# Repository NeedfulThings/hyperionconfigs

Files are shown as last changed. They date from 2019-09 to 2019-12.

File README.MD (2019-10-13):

# Hyperion uses framegrabber on Kodi
* Drives **WS2812B** Led stripes
* **45 LEDS** activated 170 incative to be activated
* **xbmcVideoChecker** is **activated** to communicate to **Kodi**
  64 * 64 Pixel @ 60 Hz
* **Smoothing** Linear 96ms @ Update Freq 48k

---

# Get the code
```BASH 
git clone --recurse-submodules
git@github.com:NeedfulThings/hyperionconfigs.git
```

# Setup the dev environment
 
We are using direnv to get a clean environment that can have oher versions than the rest of your system. It's required to set it up first and configure well.

## Install direnv

### Linux
```BASH
curl -qfsSL https://github.com/direnv/direnv/releases/download/v2.19.0/direnv.linux-amd64 -o direnv
chmod +x direnv
sudo mv direnv /usr/local/bin
```

### macOS
```BASH
brew install dirvenv
```

## Hook it up in your shell
### BASH
*add the following line to your `~/.bashrc` file*
```BASH
eval "$(direnv hook bash)"
```
### ZSH
*add the following line to your `~/.zshrc` file*
```BASH
eval "$(direnv hook zsh)"
```
### Other shells

*Take a look [here](https://github.com/direnv/direnv/blob/master/docs/hook.md)*

## Setup the dev environment by just running
```BASH
./start.sh
```
in the Project root

---

# USB Arduino Uno
Folder *USB-ArduinoUno*

* Sketch for **Arduino Uno R3**
* uses **FastLED** lib
* set to **45 LED**
* Speaks SPI on Digital **Pin 6**
* Baudrate is set to **500k baud**
* Type **adalight**
* Output to **USB Port** /ttyUSB0 
* Colororder **grb**

## Install

### `hyperion.config.json`

copy the `L45_Config/hyperion.config.json` to your `/storage/.config` folder

### `hyperion_ws2812.ino`

Install the `hyperion_ws2812.ino` on your Arduino. You can use the Makefile inside the folder by just running ```make upload```

---

# USB Arduino Nano
Folder *USB-ArduinoNano*

* Sketch for **Arduino Nano**
* uses **FastLED** lib
* set to **128 LED**
* Uses Digital **Pin 11**
* Baudrate is set to **500k baud**
* Type **adalight**
* Output to **USB Port** /ttyUSB0 
* Colororder **grb**

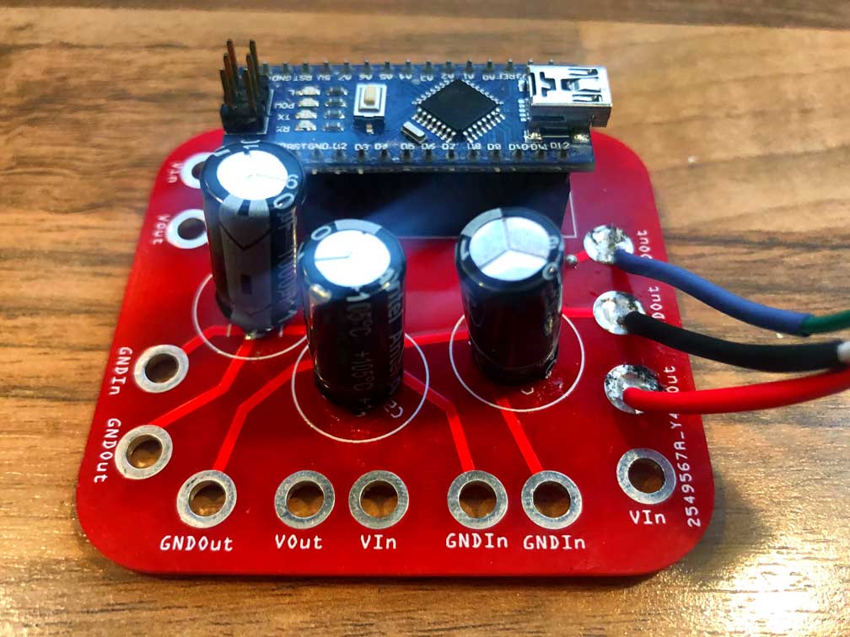
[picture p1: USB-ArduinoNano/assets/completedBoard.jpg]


## Install

### `FS128_Config`

copy the `hyperion.config.json` to your `/storage/.config` folder

### `hyperion_ws2812.ino`

Install the `hyperion_ws2812.ino` on your Arduino. You can use the Makefile inside the folder by just running ```make upload```

### `Hardware`

Take a look into the USB-ArduinoNano.md file to get more informations

---

# UDP / Network ESP8266
 Folder *UDP-ESP8266*
 * Type **udp**
 * Protocol **0**
 * Port **19446**
 * set to **45 LED** supports up to 490 inn hyperion mode

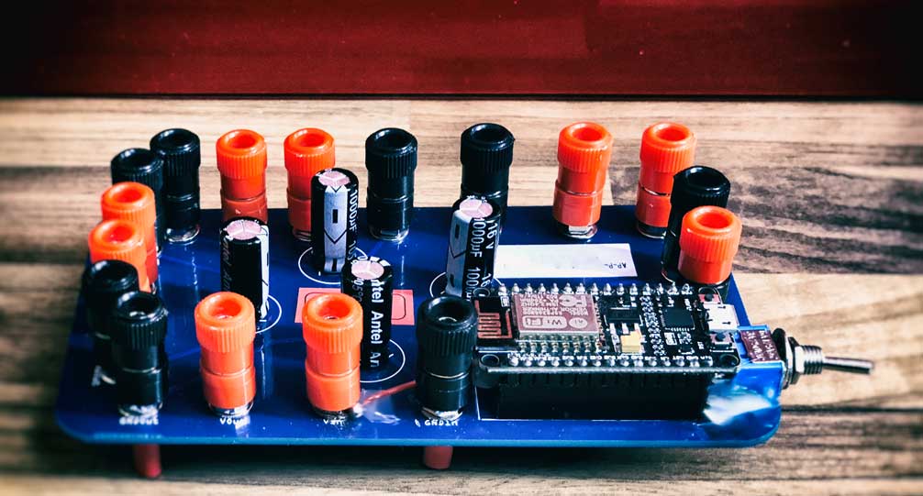
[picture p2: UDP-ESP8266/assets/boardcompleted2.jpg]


## Install

### `hyperion.config.json`

Copy the `hyperion.config.json` to your `/storage/.config` folder

### `WLED`

Install from the submobule folder [Aircoookie](https://github.com/Aircoookie)'s [WLED](https://github.com/Aircoookie/WLED) 

If you want to get it as binary you can find the latest relases [here](https://github.com/Aircoookie/WLED/releases)

Further Infos can be found in the [Wiki](htpps://github.com/Aircoookie/WLED/wiki)

---

# Directly via GPIO

 Folder *PI-GPIO*
 * Type **ws281x**
 * set to **45 LED**
 * Speaks PWM 0 on **GPIO12 (PIN 32)**
 * Colororder **grb**

## Install

### `hyperion.config.json`

copy the `hyperion.config.json` to your `/storage/.config` folder

### `SD` 

copy the `config.txt` from `SD` or at least the last lines below the `End of default configuration Block` directly to your **SD Card** while it's **NOT** running in the pi

### `etc`

copy the file `snd-blacklist.conf` to your **running** pi `/etc/modprobe.d/` - The easiest way copy etc to your / 

Now **reboot** - When your pi is up again, check with `aplay -l`if you can still see a soundcard.

If yes you might want to `blacklist snd_bcm2835` as last line to `/etc/modprobe.d/alsa-blacklist.conf`, reboot and check again.

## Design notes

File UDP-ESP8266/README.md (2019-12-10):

# Hyperion via UDP to ESP8266

## Flash Arduino
File for Arduino IDE located in `WLED`

## Setup Hyperion on PI
The `hyperion.config.json` file in this folder is setup for a 64 LED Background with no bottom.

So go get HyperCon.jar and generate a led setup what matches your setup, ignore everything else. You just need the led setup and generate a config with it. Now mark everything from 
`"leds" :`
until
`],`
and copy it. 

Go to the hyperion.config.json in this folder and replace the lines 99 - 426 with the just copied content.

Et voila, you are ready to go.
Put the file on your pi in `/storage/.config/`

## PCB & Breadboard

I created a pcb for the ESP8266 Dev Board called NodeMCU 0.9. It's a setup with 4 Power Injectors, +/- each protected by a 1000 µF capacitor leading to 4 Power Outs +/- and one Dataline connected to the D4 Port of the NodeMCU and protected with a 470Ω Resistor.

If you need to build your hardware, go to layout, there you can find:

 * Fritzing file `tvbacklightesp8266_v1.2.fzz` 

 * Gerber to get my PCB Layout manufactured

### v1.0
  * Full working layout

### v1.1
  * added Switch to power the NodeMcu with the 5V Power from the injectors

### v1.2
  * added multiple Jumper to that can be used instead of up to 3 capacitors. That enables one powerinput with all 4 power outputs for every edge of the screen.

### v1.3
  * added mountingholes
  * redesigned for a smaller form factor
  * add solderjumper

### Rendered from Gerber
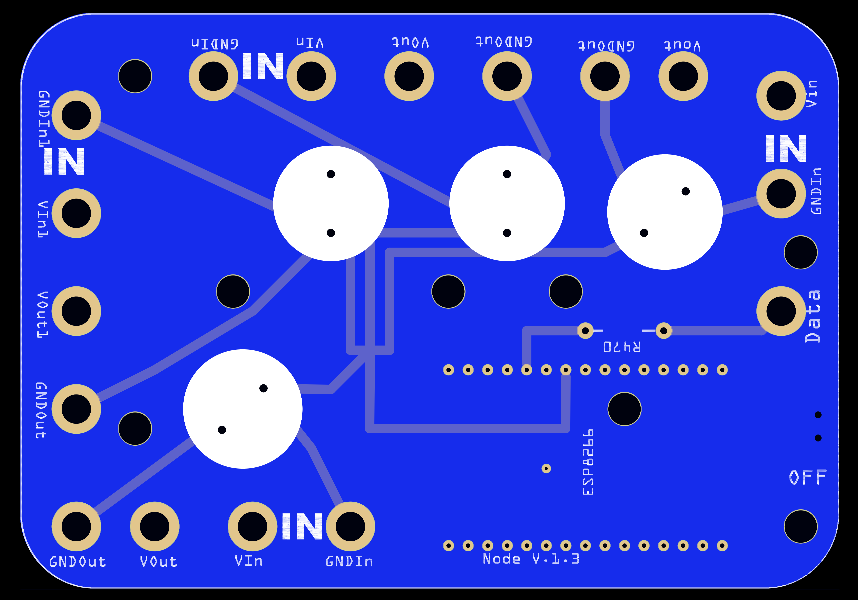
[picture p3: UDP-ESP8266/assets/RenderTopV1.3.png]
gerber_render_top_v1.3
 
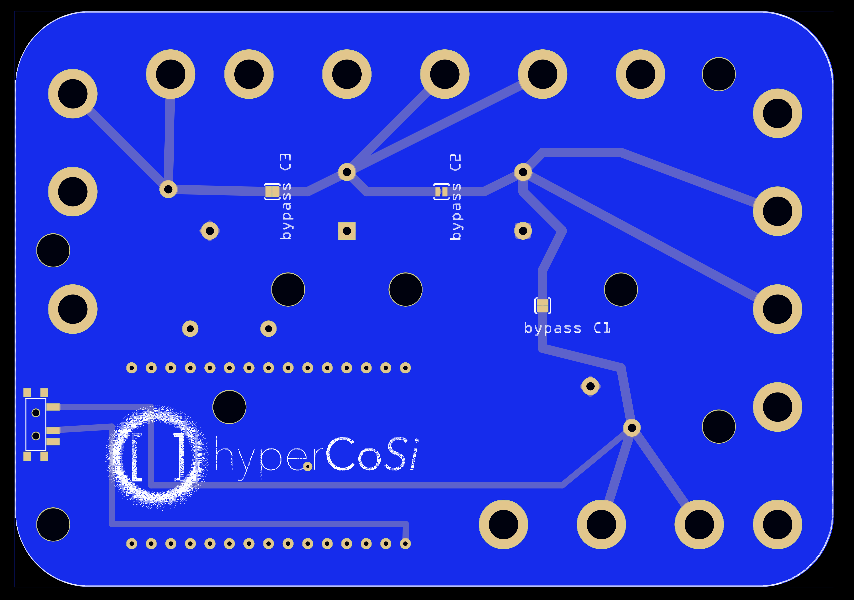
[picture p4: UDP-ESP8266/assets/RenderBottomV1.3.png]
gerber_render_bottom_v1.3

 
### Real PCBs
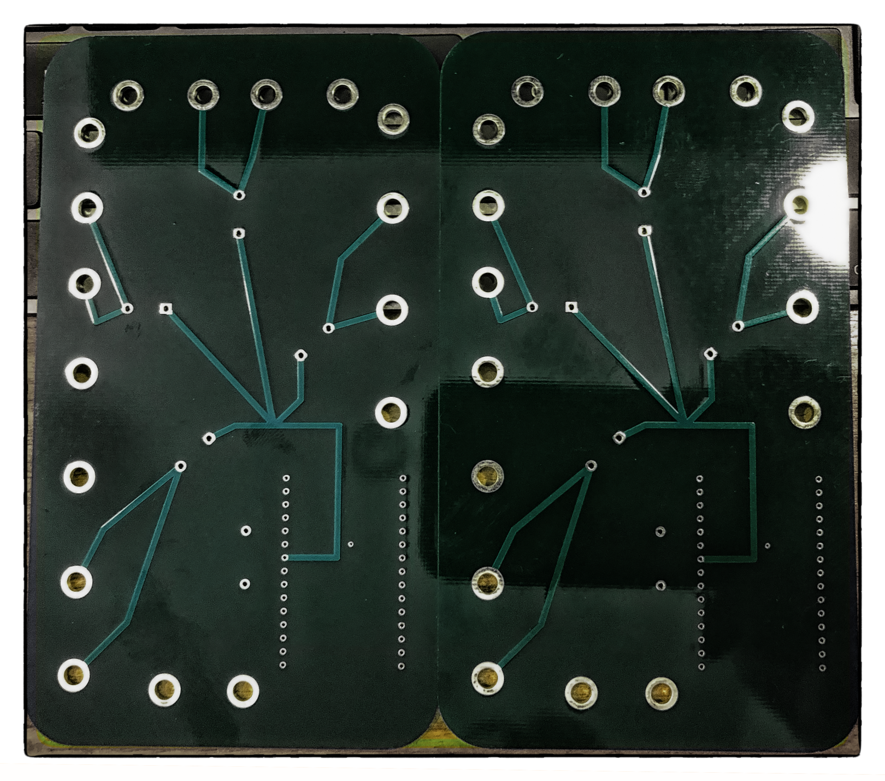
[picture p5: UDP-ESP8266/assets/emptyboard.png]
pcb_emtpy_v1.1
 

 #### Completed boards
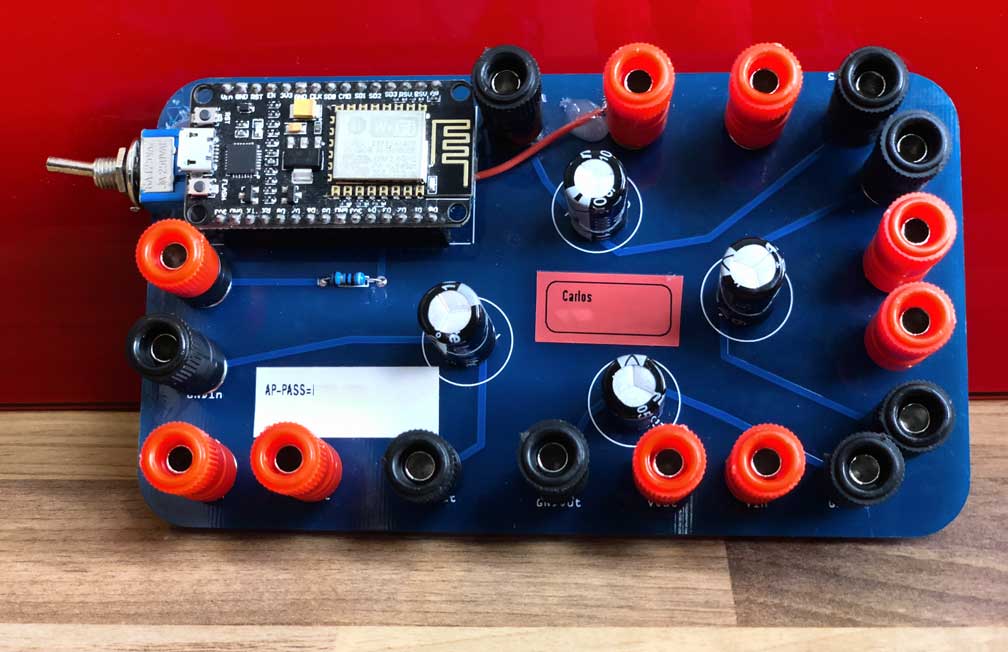
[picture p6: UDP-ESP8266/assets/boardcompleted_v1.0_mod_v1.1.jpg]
completed_board_v1.1
 
 completed_board_v1.1
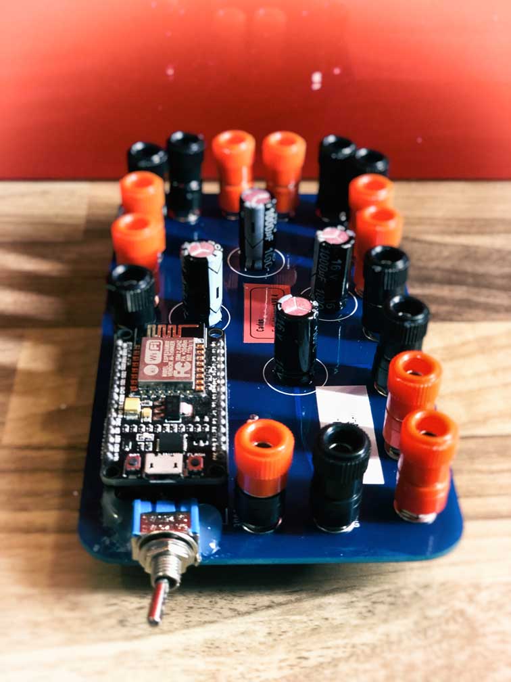
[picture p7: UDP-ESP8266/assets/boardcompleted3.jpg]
completed_board_v1.1
 

### Parts list v1.2
  * 1-4 x1000 µF capacitor
  * 0-3 Jumper
  * ESP8266 Node MCU
  * 1 Switch
  * 470Ω Resistor 
  * Receptacle socket for the Nodemcu

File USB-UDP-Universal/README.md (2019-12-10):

# Hyperion via USB/UDP to ANY

## Flash Arduino
not specified

## Setup Hyperion on PI
not specified

## PCB & Breadboard

I created a universal pcb. It's a setup with 4 Power Injectors, +/- each protected by a 1000 µF capacitor leading to 4 Power Outs +/- and one Dataline connected with a 470Ω Resistor. All Caps can be bypassed by jumpers so that less than 4 power inputs can be driven too. The controller can run selfpowered. An LED indicates standby and a switch turns it off/on. 

If you need to build your hardware, go to layout, there you can find:

 * Fritzing file `tvbacklight_v2.02.fzz` 

 * Gerber to get my PCB Layout manufactured

### v2.0(.1)
  * Full working layout

### v2.0.1
  * added mounting holes

### Rendered from Gerber
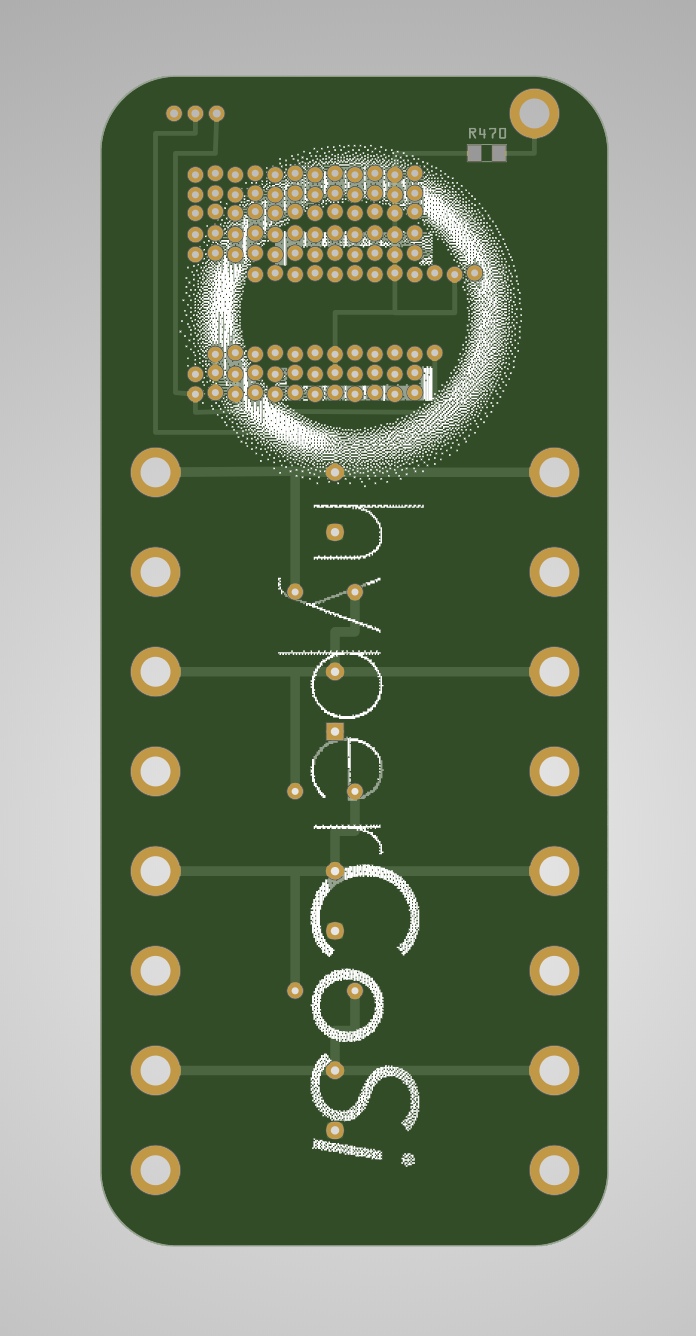
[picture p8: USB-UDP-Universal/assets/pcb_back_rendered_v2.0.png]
 
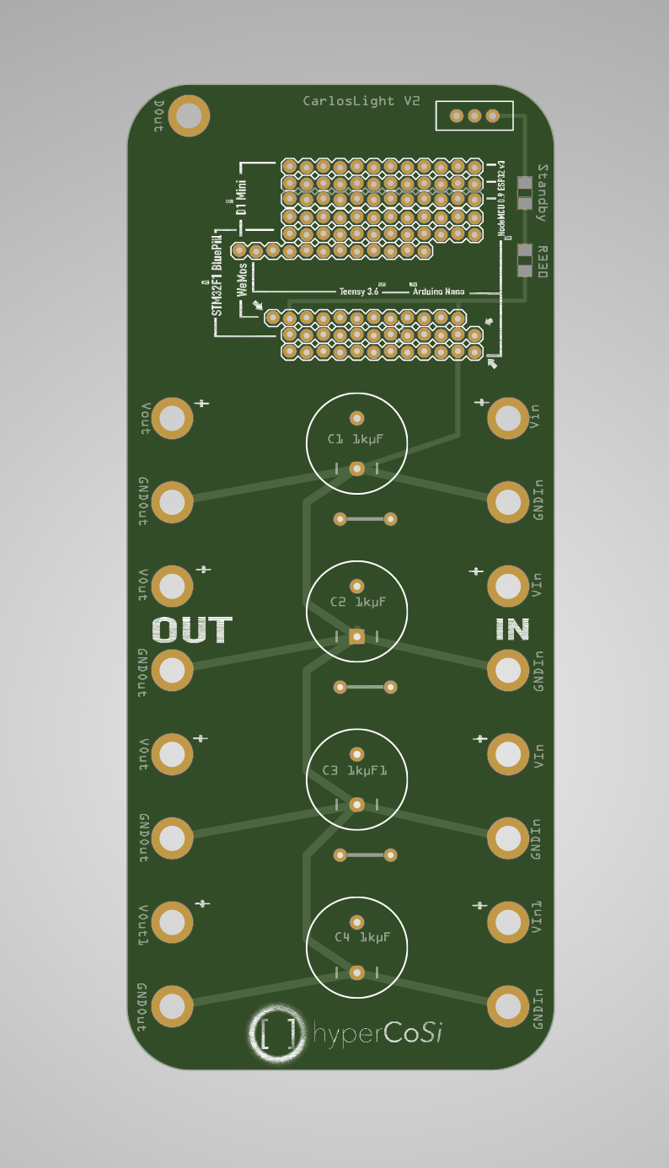
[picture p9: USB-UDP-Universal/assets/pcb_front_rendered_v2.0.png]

 
### Real PCBs
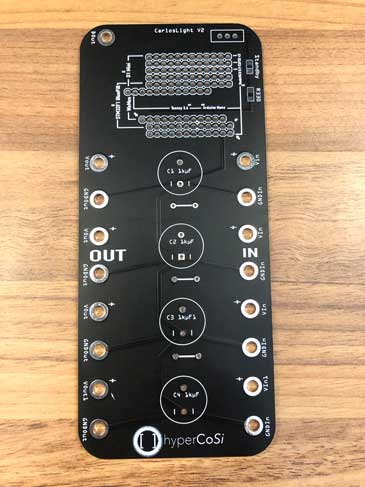
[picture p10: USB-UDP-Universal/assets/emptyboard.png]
 

 #### Completed boards
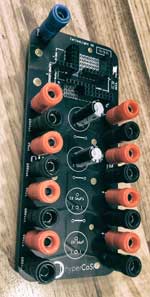
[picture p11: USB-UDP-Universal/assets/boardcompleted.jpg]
 
 
### Parts list v2.0.1
  * 1-4 x1000 µF capacitor
  * 0-3 Jumper
  * 1 Switch
  * SMD 470Ω Resistor (471)
  * SMD 330Ω Resistor (331)
  * Receptacle socket for the descired controller

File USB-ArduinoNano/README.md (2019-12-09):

# Hyperion via USB direct to Arduino Nano

## Flash Arduino
File for Arduino IDE located in `hyperion_ws2812`

## Setup Hyperion on PI
The `hyperion.config.json` file in `F128_Config` is setup for a 128 LED Background with no bottom.

So go get HyperCon.jar and generate a led setup what matches your setup, ignore everything else. You just need the led setup and generate a config with it. Now mark everything from 
`"leds" :`
until
`],`
and copy it. 

Go to the hyperion.config.json in F128_Config and replace the lines 96 - 743 with the just copied content.

Et voila, you are ready to go.
Put the file on your pi in `/storage/.config/`

## PCB & Breadboard

I created a pcb for the Arduino Nano setup with 3 Power Injectors, +/- each protected by a 1000 µF capacitor leading to 3 Power Outs +/- and one Dataline connected to the D11 Port of the Nano and protected with a 470Ω Resistor.

If you need to build your hardware, go to layout, there you can find:

 * Fritzing file `tvbacklightnano.fzz`
 * Gerber to get my PCB Layout manufactured
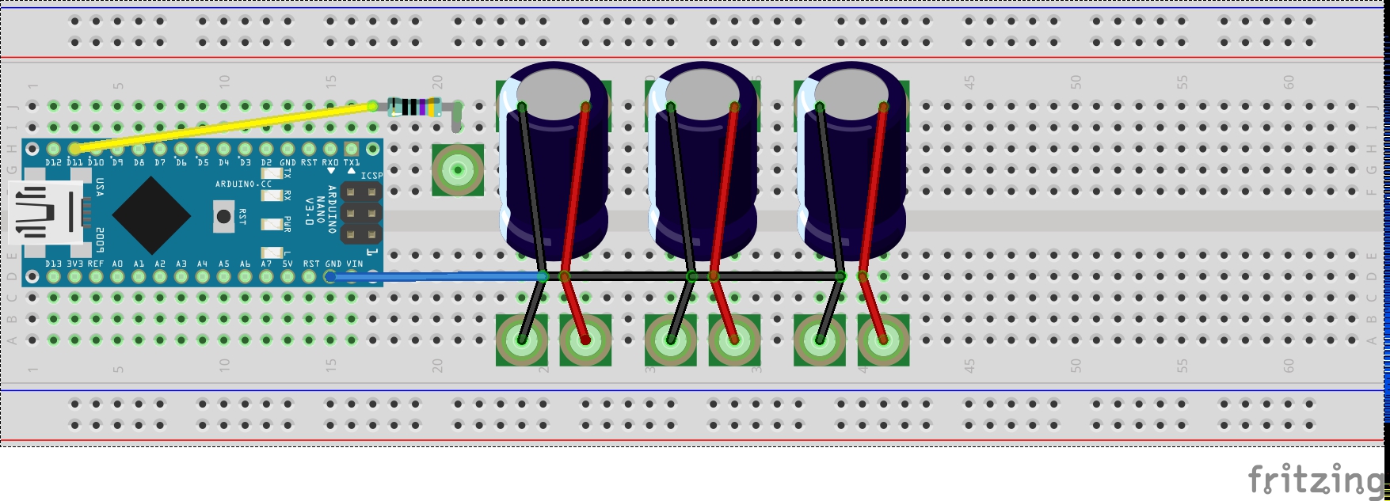
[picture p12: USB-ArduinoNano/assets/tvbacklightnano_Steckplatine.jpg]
 

### Rendered from Gerber
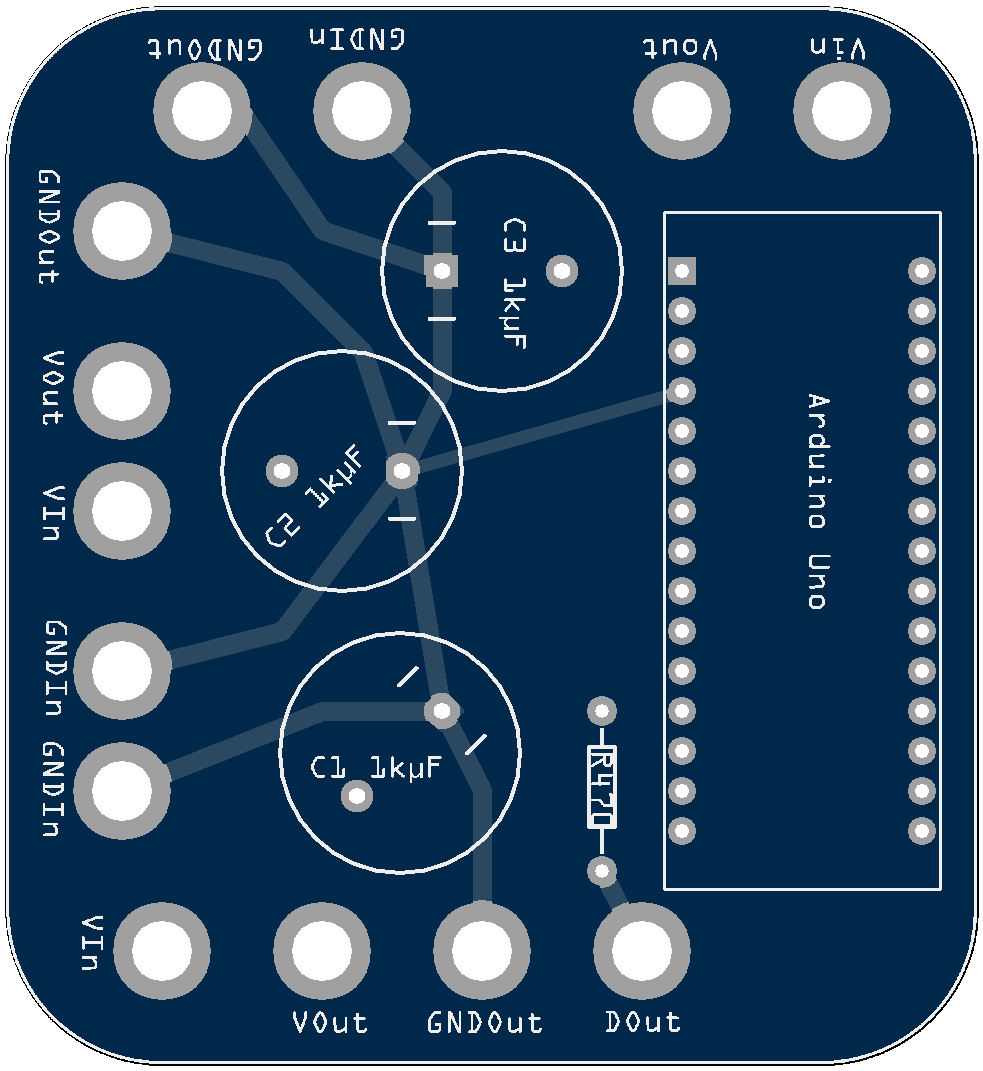
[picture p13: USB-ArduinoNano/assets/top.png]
 
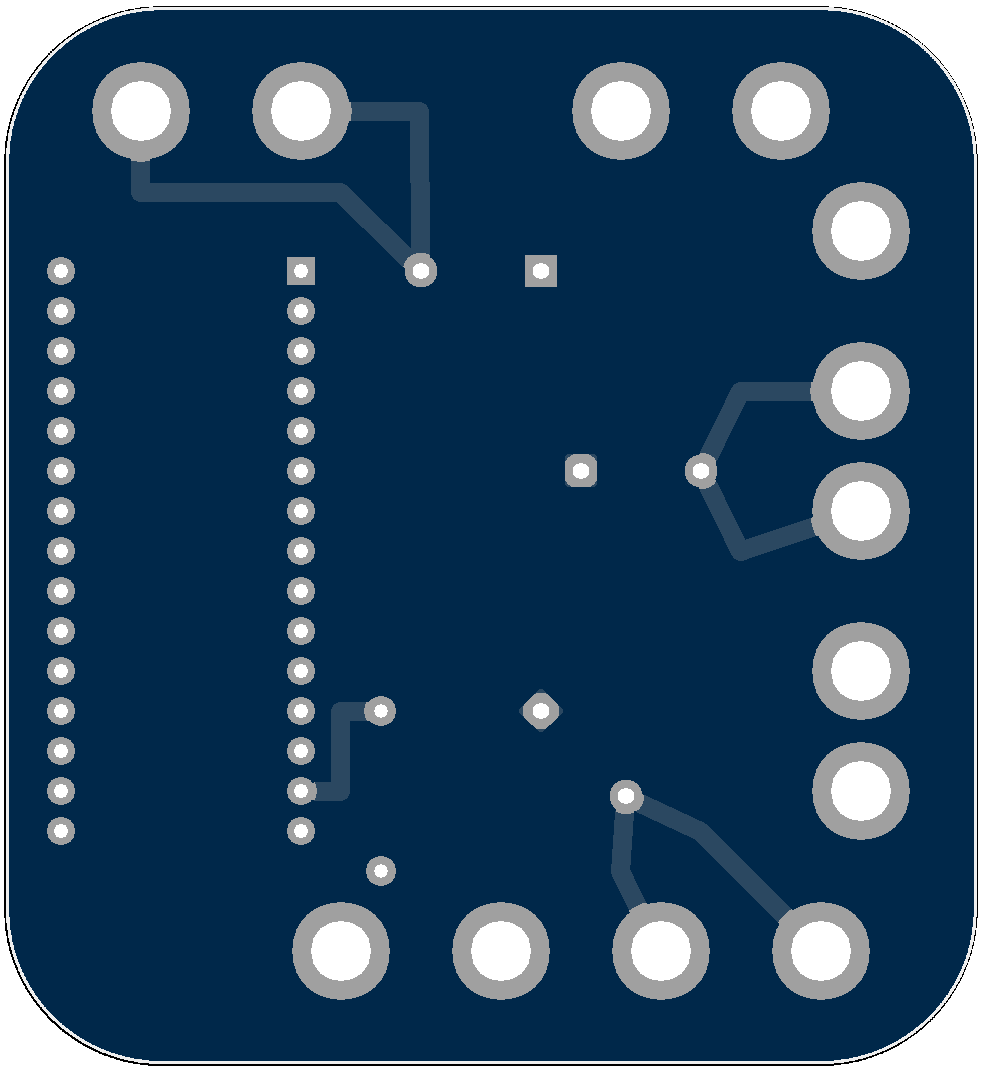
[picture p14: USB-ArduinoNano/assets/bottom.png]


### Real PCBs
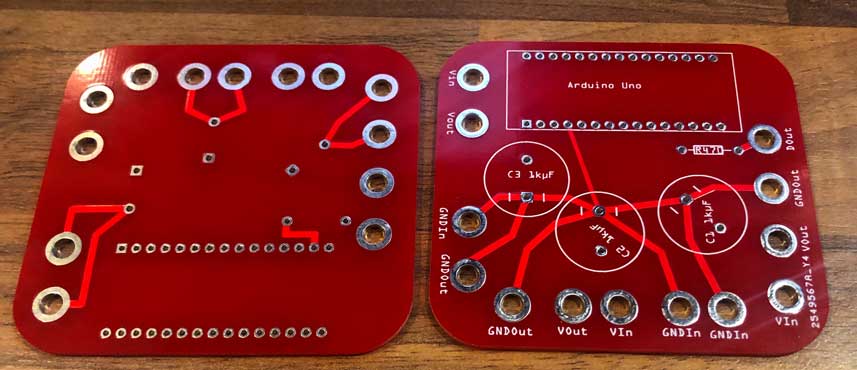
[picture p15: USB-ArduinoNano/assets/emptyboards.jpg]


### Complete assebled Board


### Parts list
  * 3 x1000 µF capacitor
  * Arduino Nano
  * 470Ω Resistor 
  * Receptacle socket for the nano

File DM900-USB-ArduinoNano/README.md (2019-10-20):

# Enigmalight Plugin for DM900 and DM920

The Plugin depends on [Dima73/enigmalight](https://github.com/Dima73/enigmalight) => [Speedy1985/enigmalight](https://github.com/Speedy1985/enigmalight)
* enigma2-plugin-extensions-enigmalight_0.4-rc1-dm900-dm920.deb 
* DM900-Enigmalight-Service

## Installation copy the dep into /tmp on your system and install it 
```shell
  sudo dpkg -i enigma2-plugin-extensions-enigmalight_0.4-rc1-dm900-dm920.deb
```

# Arduino Sketch

  Just upload it like in the other versions.

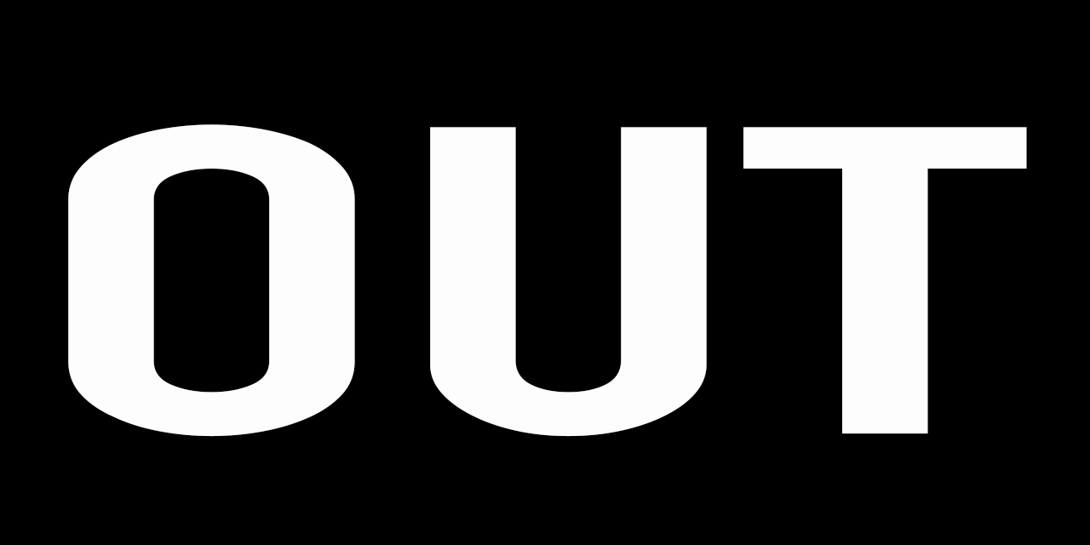
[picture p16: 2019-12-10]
USB-UDP-Universal/layout/assets/out_i.png

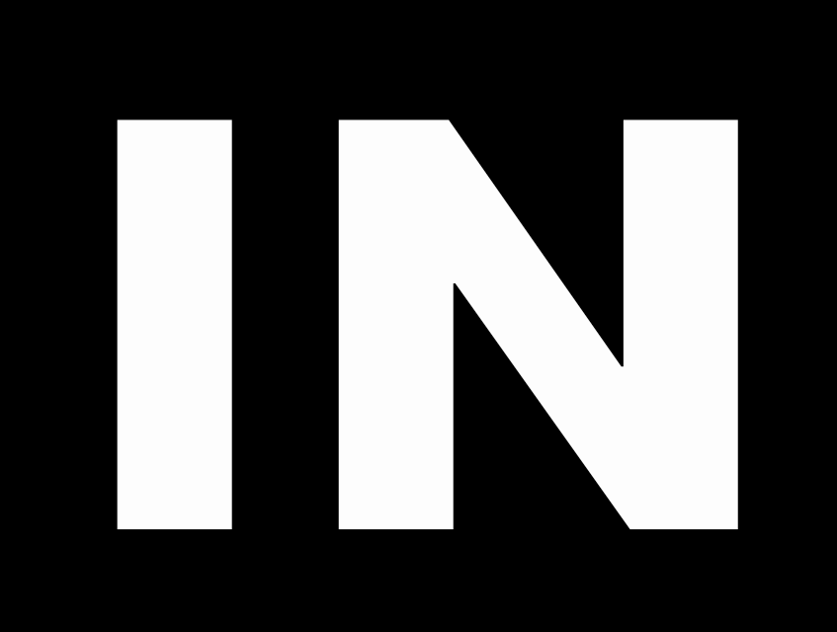
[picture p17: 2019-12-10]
USB-UDP-Universal/layout/assets/IN_I.png

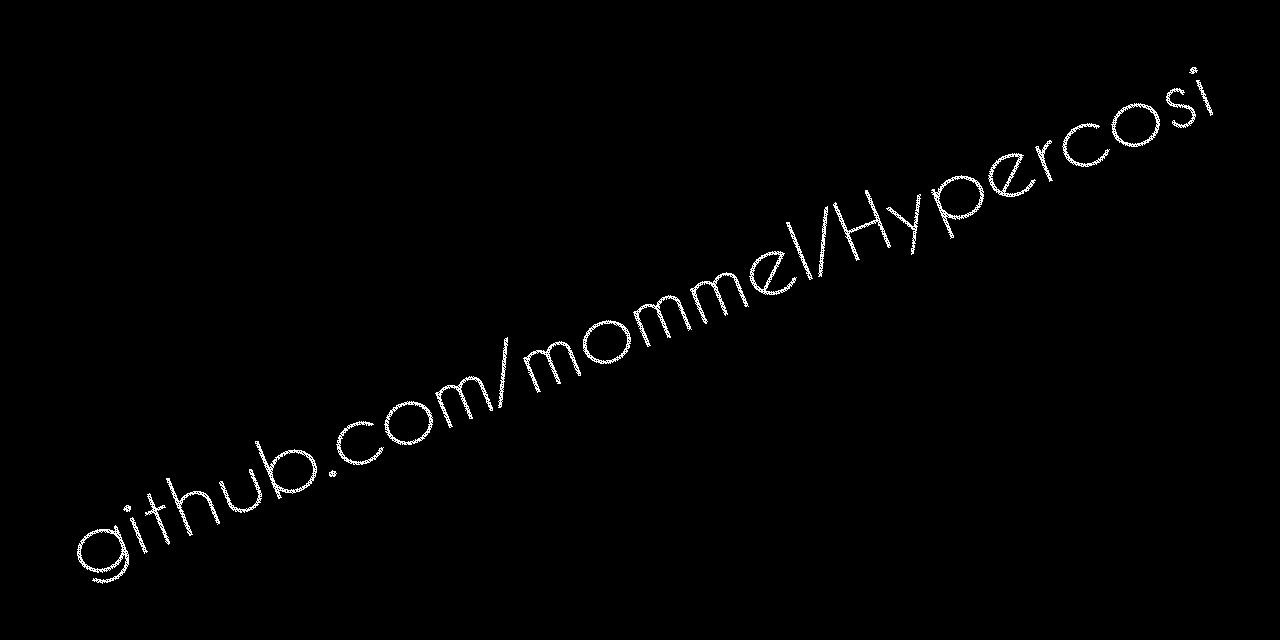
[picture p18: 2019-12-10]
USB-UDP-Universal/layout/assets/back_i.png

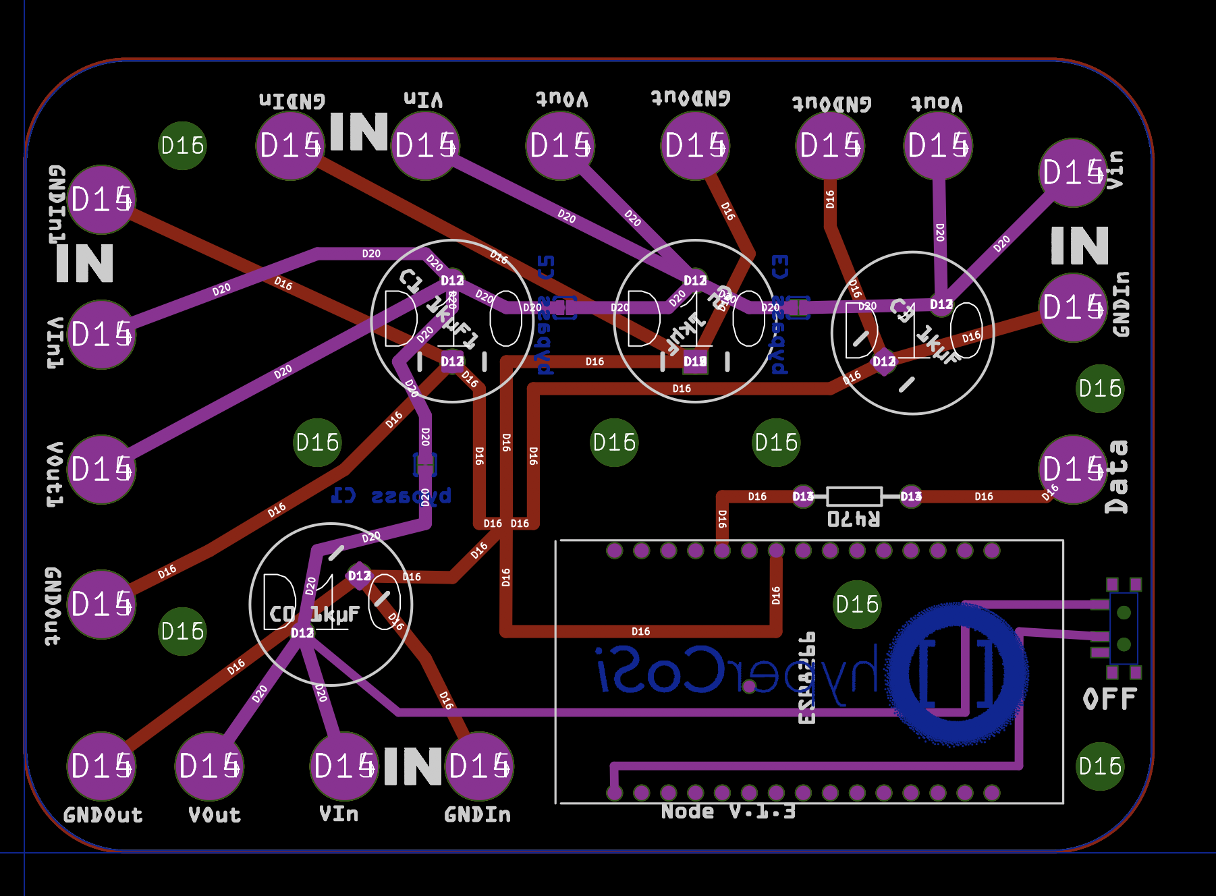
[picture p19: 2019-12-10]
UDP-ESP8266/assets/Gerberv1.3.png

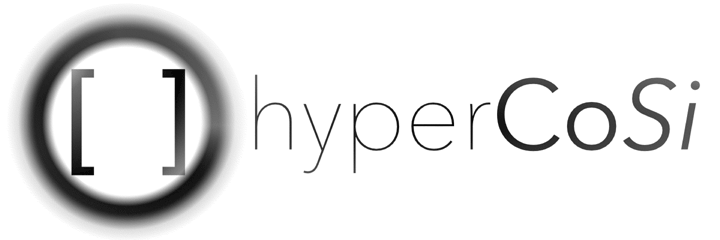
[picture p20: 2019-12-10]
USB-UDP-Universal/layout/assets/hypercosi.png

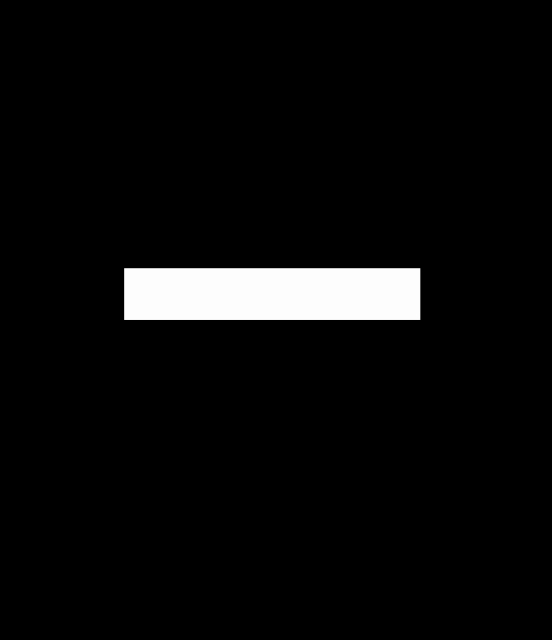
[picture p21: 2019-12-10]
USB-UDP-Universal/layout/assets/minus-i.png

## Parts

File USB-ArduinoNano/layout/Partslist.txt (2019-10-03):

  v1.0
  * 4 x1000 µF capacitor
  * NodeMCU ESP8266
  * 100Ω Resistor 
  * Receptacle socket for the nano
  -----
  v1.1
  * 1 Switch

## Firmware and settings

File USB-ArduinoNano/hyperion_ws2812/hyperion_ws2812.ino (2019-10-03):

#include "FastLED.h"
 
// How many leds in your strip?
#define NUM_LEDS 77
 
// For led chips like Neopixels, which have a data line, ground, and power, you just
// need to define DATA_PIN.  For led chipsets that are SPI based (four wires - data, clock,
// ground, and power), like the LPD8806 define both DATA_PIN and CLOCK_PIN
#define DATA_PIN 11
#define CLOCK_PIN 13
 
#define COLOR_ORDER RGB
 
// Adalight sends a "Magic Word" (defined in /etc/boblight.conf) before sending the pixel data
uint8_t prefix[] = {'A', 'd', 'a'}, hi, lo, chk, i;
 
// Baudrate, higher rate allows faster refresh rate and more LEDs (defined in /etc/boblight.conf)
#define serialRate 460800
 
// Define the array of leds
CRGB leds[NUM_LEDS];

void RGBLoop(){
  for(int j = 0; j < 3; j++ ) {
    // Fade IN
    for(int k = 0; k < 256; k=k+3) {
      switch(j) {
        case 0: LEDS.showColor(CRGB(k,0,0)); break;
        case 1: LEDS.showColor(CRGB(0,k,0)); break;
        case 2: LEDS.showColor(CRGB(0,0,k)); break;
      }
      delay(1);
    }
    // Fade OUT
    for(int k = 255; k >= 0; k=k-3) {
      switch(j) {
        case 0: LEDS.showColor(CRGB(k,0,0)); break;
        case 1: LEDS.showColor(CRGB(0,k,0)); break;
        case 2: LEDS.showColor(CRGB(0,0,k)); break;
      }
      delay(1);
    }
  }
  FastLED.show();
  leds[1].r = 254;
  leds[NUM_LEDS-1].r = 254;
  FastLED.show();
  delay(128);
  for(int l = 0; l < NUM_LEDS; l++) {
    leds[l].b = 254;
    FastLED.show();
    delay(2);
    leds[l].b = 0;
   }  
  leds[1].r = 0;
  leds[NUM_LEDS-1].r = 0;
  FastLED.show();
}

void setup() {
      // Uncomment/edit one of the following lines for your leds arrangement.
      // FastLED.addLeds<TM1803, DATA_PIN, RGB>(leds, NUM_LEDS);
      // FastLED.addLeds<TM1804, DATA_PIN, RGB>(leds, NUM_LEDS);
      // FastLED.addLeds<TM1809, DATA_PIN, RGB>(leds, NUM_LEDS);
      // FastLED.addLeds<WS2811, DATA_PIN, RGB>(leds, NUM_LEDS);
      // FastLED.addLeds<WS2812, DATA_PIN, RGB>(leds, NUM_LEDS);
         FastLED.addLeds<WS2812B, DATA_PIN, RGB>(leds, NUM_LEDS);
      // FastLED.addLeds<NEOPIXEL, DATA_PIN>(leds, NUM_LEDS);
      // FastLED.addLeds<UCS1903, DATA_PIN, RGB>(leds, NUM_LEDS);
      // FastLED.addLeds<UCS1903B, DATA_PIN, RGB>(leds, NUM_LEDS);
      // FastLED.addLeds<GW6205, DATA_PIN, RGB>(leds, NUM_LEDS);
      // FastLED.addLeds<GW6205_400, DATA_PIN, RGB>(leds, NUM_LEDS);
     
      // FastLED.addLeds<WS2801, RGB>(leds, NUM_LEDS);
      // FastLED.addLeds<SM16716, RGB>(leds, NUM_LEDS);
      // FastLED.addLeds<LPD8806, RGB>(leds, NUM_LEDS);
 
      // FastLED.addLeds<WS2801, DATA_PIN, CLOCK_PIN, RGB>(leds, NUM_LEDS);
      // FastLED.addLeds<SM16716, DATA_PIN, CLOCK_PIN, RGB>(leds, NUM_LEDS);
      // FastLED.addLeds<LPD8806, DATA_PIN, CLOCK_PIN, RGB>(leds, NUM_LEDS);
     
        // initial RGB Cycle
        RGBLoop();
       
        Serial.begin(serialRate);
        Serial.print("Ada\n"); // Send "Magic Word" string to host
 
}
 
void loop() {
  // wait for first byte of Magic Word
  for(i = 0; i < sizeof prefix; ++i) {
    waitLoop: while (!Serial.available()) ;;
    // Check next byte in Magic Word
    if(prefix[i] == Serial.read()) continue;
    // otherwise, start over
    i = 0;
    goto waitLoop;
  }
 
  // Hi, Lo, Checksum
 
  while (!Serial.available()) ;;
  hi=Serial.read();
  while (!Serial.available()) ;;
  lo=Serial.read();
  while (!Serial.available()) ;;
  chk=Serial.read();
 
  // if checksum does not match go back to wait
  if (chk != (hi ^ lo ^ 0x55))
  {
    i=0;
    goto waitLoop;
  }
 
  memset(leds, 0, NUM_LEDS * sizeof(struct CRGB));
  // read the transmission data and set LED values
  for (uint8_t i = 0; i < NUM_LEDS; i++) {
    byte r, g, b;    
    while(!Serial.available());
    r = Serial.read();
    while(!Serial.available());
    g = Serial.read();
    while(!Serial.available());
    b = Serial.read();
    leds[i].r = r;
    leds[i].g = g;
    leds[i].b = b;
  }
  // shows new values
 FastLED.show();
}

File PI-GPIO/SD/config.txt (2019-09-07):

################################################################################
#      This file is part of OpenELEC - http://www.openelec.tv
#      Copyright (C) 2009-2017 Stephan Raue (stephan@openelec.tv)
#      Inspired and partly copied from:
#  http://youresuchageek.blogspot.fr/2012/09/howto-raspberry-pi-openelec-on.html
#
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
#  You should have received a copy of the GNU General Public License
#  along with OpenELEC.  If not, see <http://www.gnu.org/licenses/>.
################################################################################
# Bootloader configuration - config.txt
################################################################################

################################################################################
# Memory (System/GPU configuration )
################################################################################

# default GPU memory split (do not change if you do not know what you are doing)
  gpu_mem=128

# SDRAM size based GPU memory split, uncomment and setup to override 'gpu_mem'
  gpu_mem_256=112
  gpu_mem_512=160
  gpu_mem_1024=256

################################################################################
# Overclocking settings
# WARNING: Do not change/enable if you do not know what you are doing!
#          The System may become unstable or you can have data corruption or
#          you can loose your warranty if you set wrong settings
#
# please read: http://elinux.org/RPi_config.txt#Overclocking_configuration
################################################################################

# Overclock mode settings.
#
# default recommended values are: arm_freq | core_freq | sdram_freq | over_voltage
# no overclocking               :    700   |    250    |    400     |      0
# mode 'Modest'                 :    800   |    300    |    400     |      0
# mode 'Medium'                 :    900   |    333    |    450     |      2
# mode 'High'                   :    950   |    450    |    450     |      6
# mode 'Turbo'                  :   1000   |    500    |    600     |      6
# mode 'Pi2'                    :   1000   |    500    |    500     |      2

# arm_freq=700
# core_freq=250
# sdram_freq=400
# over_voltage=0

# set to 'force_turbo=1' to disable dynamic overclocking (you can lose your warranty!)
  force_turbo=0

# If you have any data corruption using Turbo Mode and overclocking
# try with this setting uncommented
# If this still fails, try to use Medium mode without "over_voltage=2"
# If it ultimately keeps failing, forget about this until it gets fixed
# Use a more conservative mode that will works fine in any cases:
# initial_turbo=30

################################################################################
# Overscan settings
################################################################################

# Make display smaller to stop text spilling off the screen
# see also http://www.raspberrypi.org/phpBB3/viewtopic.php?f=67&t=15700
# overscan_scale=1
# disable_overscan=1

# Adapt overscan values to your needs
# overscan_left=57
# overscan_right=59
# overscan_top=20
# overscan_bottom=20

################################################################################
# various settings see also: http://elinux.org/RPi_config.txt
################################################################################

# Force HDMI even if unplugged or powered off
# hdmi_force_hotplug=1

# Doesn't sent initial active source message.
# Avoids bringing CEC (enabled TV) out of standby and channel switch when
# rebooting.
  hdmi_ignore_cec_init=1

################################################################################
# License keys to enable GPU hardware decoding for various codecs
# to obtain keys visit the shop at http://www.raspberrypi.com
################################################################################

# decode_MPG2=0x00000000
# decode_WVC1=0x00000000
# decode_DTS=0x00000000
# decode_DDP=0x00000000

################################################################################
# End of default configuration
# all values below this line were inserted from config.txt.bk (your old config)
# and can be merged with the above values
################################################################################
dtparam=spi=on
hdmi_force_hotplug=1
hdmi_force_edid_audio=1
#Increase UART speed
init_uart_clock=14745600
dtparam=spi=on

# ON RASPI 3 uncomment the following 
# core_freq=250

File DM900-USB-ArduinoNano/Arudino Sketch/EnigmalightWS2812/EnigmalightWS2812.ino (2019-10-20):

/* 
 * Enigmalight WS2812B
 * Talk enigmalight to the Arduino Nano
*/
static const uint8_t 
  Num_Leds   =  62,
  Led_Pin    =  11,
  Brightness =  255;
#define LED_TYPE     WS2812B 
#define COLOR_ORDER  GRB     
static const unsigned long
  SerialSpeed    = 115200, 
  SerialTimeout  = 150000;
#define CLEAR_ON_START
#include <FastLED.h>
CRGB leds[Num_Leds];
uint8_t * ledsRaw = (uint8_t *)leds;
static const uint8_t magic[] = {
  'A','d','a'};
#define MAGICSIZE  sizeof(magic)
#define HICHECK    (MAGICSIZE)
#define LOCHECK    (MAGICSIZE + 1)
#define CHECKSUM   (MAGICSIZE + 2)
#define MODE_HEADER 0
#define MODE_DATA   1
void setup(){
  FastLED.addLeds<LED_TYPE, Led_Pin, COLOR_ORDER>(leds, Num_Leds);
  FastLED.setBrightness(Brightness);
  #ifdef CLEAR_ON_START
    FastLED.show();
  #endif
  Serial.begin(SerialSpeed);
  enigmalight();
}

void enigmalight(){ 
  uint8_t
    mode = MODE_HEADER,
    headPos,
    hi, lo, chk;
  int16_t
    c;
  uint16_t
    outPos;
  uint32_t
    bytesRemaining;
  unsigned long
    lastByteTime,
    lastAckTime,
    t;
  Serial.print("Ada\n");
  lastByteTime = lastAckTime = millis();
  for(;;) {
    t = millis();    
    if((c = Serial.read()) >= 0){
      lastByteTime = lastAckTime = t;       
      switch(mode) {  
      case MODE_HEADER:
        if(headPos < MAGICSIZE){
          if(c == magic[headPos]) headPos++;
          else headPos = 0;
        }
        else{
          switch(headPos){
            case HICHECK:
              hi = c;
              headPos++;
              break;
            case LOCHECK:
              lo = c;
              headPos++;
              break;
            case CHECKSUM:
              chk = c;
              if(chk == (hi ^ lo ^ 0x55)) {
                bytesRemaining = 3L * (256L * (long)hi + (long)lo + 1L);
                outPos = 0;
                memset(leds, 0, Num_Leds * sizeof(struct CRGB));
                mode = MODE_DATA; 
              }
              headPos = 0;
              break;
          }
        }
        break;
        case MODE_DATA:
        if(bytesRemaining > 0) {
          if (outPos < sizeof(leds)){
            #ifdef CALIBRATE
              if(outPos < 3)
                ledsRaw[outPos++] = c;
              else{
                ledsRaw[outPos] = ledsRaw[outPos%3];
                outPos++;
              }
            #else
              ledsRaw[outPos++] = c; 
            #endif
          }
          bytesRemaining--;
        }
        if(bytesRemaining == 0) {
          mode = MODE_HEADER;
          FastLED.show();
        }
        break;
      } 
    } 
    else {
      if((t - lastAckTime) > 1000) {
        Serial.print("Ada\n"); 
        lastAckTime = t; 
      }
      if((t - lastByteTime) > SerialTimeout) {
        memset(leds, 0, Num_Leds * sizeof(struct CRGB)); 
        FastLED.show();
        lastByteTime = t;
      }
    }
  } 
}

void loop()
{}

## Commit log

2019-10-03 add USB Nano setup
    Added USB Nano INO, hyperion.config and layout for pcb with partslist
    [tvbacklightnano.fzz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]
2019-10-03 Readme updated for USB-ArduinoNano
2019-10-03 add pcb for 8266
    [tvbacklightesp82661.0.fzz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]
2019-10-20 Add enigmalight dm900 arduino nano
2019-12-10 adds Universal USB UDP PCB with readme
    [tvbacklight_v2.01.fzz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]
2019-12-10 adds Readme and new Layout to ESP8266
    [tvbacklightesp8266_v1.2.fzz, tvbacklightesp8266_v1.3.fzz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]
